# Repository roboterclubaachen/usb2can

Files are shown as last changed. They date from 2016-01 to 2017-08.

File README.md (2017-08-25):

# usb2can: Compact, isolated USB to CAN Adaptor <span style="float:right;"></span>

USB2CAN is a compact, USB-based and isolated CAN adaptor.

It is based on

 * STM32F072 Crystal-less STM32F072 ARM Cortex-M0 Processor
 * ADM3053 Isolated CAN Transceiver

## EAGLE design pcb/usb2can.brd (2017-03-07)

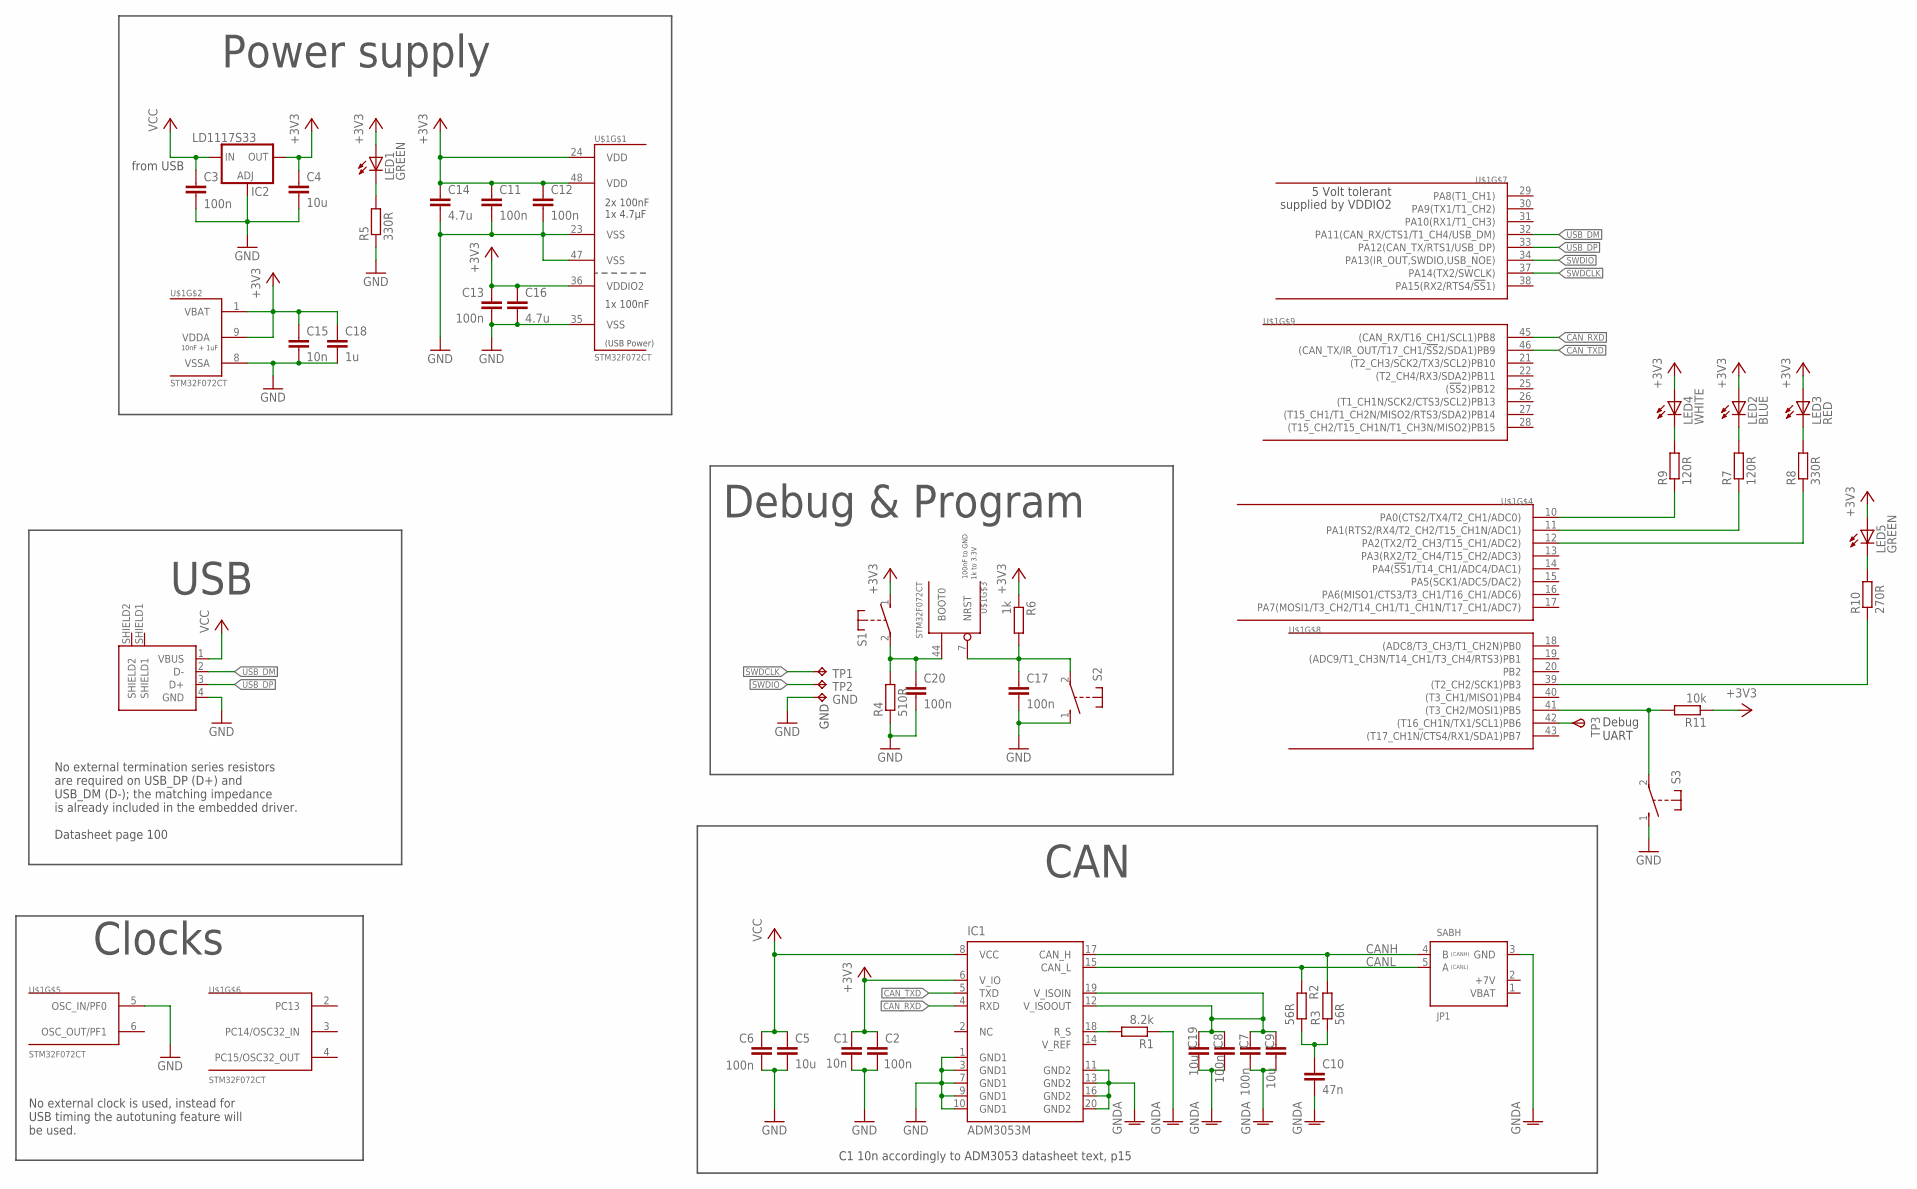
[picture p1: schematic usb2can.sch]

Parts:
C1: 10n; C0603K
C2, C3, C6: 100n; C0603K
C4, C5, C9, C19: 10u; C0805K
C7, C8: 100n; C0805K
C10: 47n; C0603K
C11, C12, C13, C17, C20: 100n; C0603
C14, C16: 4.7u; C0805K
C15: 10n; C0603
C18: 1u; C0805K
CON1: USB_A_MALESMD; USB_A_MALE_SMD
GND: TPB2,54; B2,54
IC1: ADM3053M; SO20W
IC2: LD1117S33; SOT223
JP1: SABH; 7395-05
LED1, LED5: GREEN; CHIPLED_0603
LED2: BLUE; CHIPLED_0603
LED3: RED; CHIPLED_0603
LED4: WHITE; CHIPLED_0603
R1: 8.2k; R0603
R2, R3: 56R; R0805
R4: 510R; R0603
R5, R8: 330R; R0603
R6: 1k; R0603
R7, R9: 120R; R0603
R10: 270R; R0603
R11: 10k; R0603
S1, S2, S3: MICRO_SWITCH_3X6X2.5S; MICRO_SWITCH_3X6X2.5
TP1, TP2: TPB2,54; B2,54
TP3: TPSTP07R; TP07R
U$1: STM32F072CT; TQFP48

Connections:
+3V3: C1.1, C2.1, C4.1, C11.1, C12.1, C13.1, C14.1, C15.1, C16.1, C18.1, IC1.6 (V_IO), IC2.4 (OUT), LED1.A, LED2.A, LED3.A, LED4.A, LED5.A, R6.1, R11.1, S1.1, U$1.1 (VBAT), U$1.9 (VDDA), U$1.24 (VDD), U$1.36 (VDDIO2), U$1.48 (VDD)
CANH: IC1.17 (CAN_H), JP1.4 (B), R3.2
CANL: IC1.15 (CAN_L), JP1.5 (A), R2.2
CAN_RXD: IC1.4 (RXD), U$1.45 ((CAN_RX/T16_CH1/SCL1)PB8)
CAN_TXD: IC1.5 (TXD), U$1.46 ((CAN_TX/IR_OUT/T17_CH1/!SS!2/SDA1)PB9)
GND: C1.2, C2.2, C3.2, C4.2, C5.2, C6.2, C11.2, C12.2, C13.2, C14.2, C15.2, C16.2, C17.2, C18.2, C20.2, CON1.4 (GND), GND.TP, IC1.1 (GND1), IC1.3 (GND1), IC1.7 (GND1), IC1.9 (GND1), IC1.10 (GND1), IC2.1 (ADJ), R4.1, R5.1, S2.1, S3.1, U$1.5 (OSC_IN/PF0), U$1.8 (VSSA), U$1.23 (VSS), U$1.35 (VSS), U$1.47 (VSS)
GNDA: C7.2, C8.2, C9.2, C10.2, C19.2, IC1.11 (GND2), IC1.13 (GND2), IC1.16 (GND2), IC1.20 (GND2), JP1.3 (GND), R1.1
unnamed: IC1.18 (R_S), R1.2
unnamed: C10.1, R2.1, R3.1
unnamed: LED1.C, R5.2
unnamed: C20.1, R4.2, S1.2, U$1.44 (BOOT0)
unnamed: C17.1, R6.2, S2.2, U$1.7 (NRST)
unnamed: C7.1, C8.1, C9.1, C19.1, IC1.12 (V_ISOOUT), IC1.19 (V_ISOIN)
unnamed: LED2.C, R7.2
unnamed: R11.2, S3.2, U$1.41 ((T3_CH2/MOSI1)PB5)
unnamed: LED3.C, R8.2
unnamed: LED4.C, R9.2
unnamed: R9.1, U$1.10 (PA0(CTS2/TX4/T2_CH1/ADC0))
unnamed: R7.1, U$1.11 (PA1(RTS2/RX4/T2_CH2/T15_CH1N/ADC1))
unnamed: R8.1, U$1.12 (PA2(TX2/T2_CH3/T15_CH1/ADC2))
unnamed: LED5.C, R10.2
unnamed: R10.1, U$1.39 ((T2_CH2/SCK1)PB3)
SWDCLK: TP1.TP, U$1.37 (PA14(TX2/SWCLK))
SWDIO: TP2.TP, U$1.34 (PA13(IR_OUT,SWDIO,USB_NOE))
TX: TP3.TP, U$1.42 ((T16_CH1N/TX1/SCL1)PB6)
USB_DM: CON1.2 (D-), U$1.32 (PA11(CAN_RX/CTS1/T1_CH4/USB_DM))
USB_DP: CON1.3 (D+), U$1.33 (PA12(CAN_TX/RTS1/USB_DP))
VCC: C3.1, C5.1, C6.1, CON1.1 (VBUS), IC1.8 (VCC), IC2.3 (IN)

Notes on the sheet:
CAN
No external termination series resistors are required on USB_DP (D+) and USB_DM (D-); the matching impedance is already included in the embedded driver. Datasheet page 100
USB
Clocks
No external clock is used, instead for USB timing the autotuning feature will be used.
from USB
Power supply
Debug & Program
Debug UART
C1 10n accordingly to ADM3053 datasheet text, p15

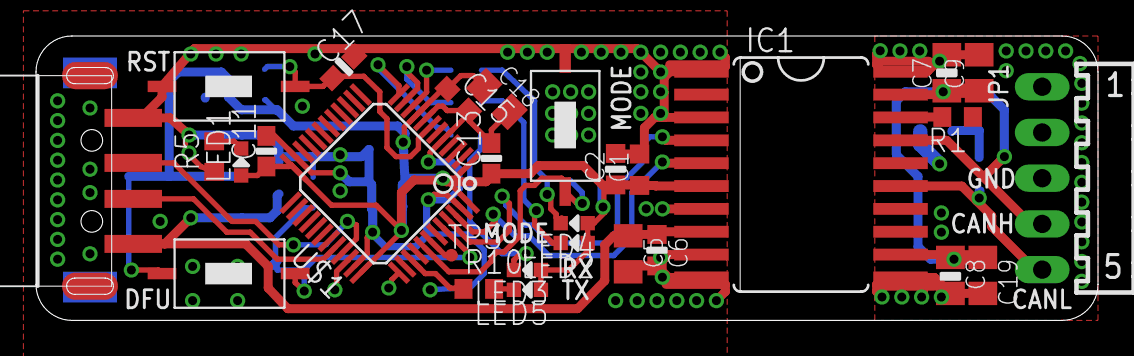
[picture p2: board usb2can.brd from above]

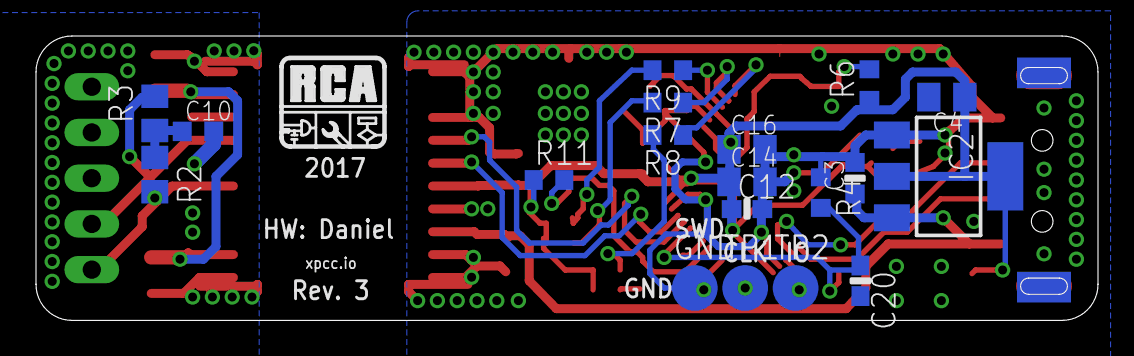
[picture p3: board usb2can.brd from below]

Board: 2 copper layers, 59.0 x 15.8 mm, 49 parts (19 on the bottom side), 28 nets.

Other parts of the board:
U$2: LOGO_SILK_BOT

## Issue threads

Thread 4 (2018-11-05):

Voltage ratings of capacitors C7, C8, C9 and C19

strongly-typed, 2018-11-05:
C7, C8, C9 and C19 are in a 0805 package. Is there a special requirement? What voltage rating has been selected in the successful prototypes? What ceramic (X7R?) is recommended?

salkinium, 2018-11-05:
cc @daniel-k @ekiwi

ekiwi, 2018-11-05:
I think the hardware was mostly done by @daniel-k.

daniel-k, 2018-11-18:
Hum, it's been quite some time and I honestly don't remeber, sorry :/

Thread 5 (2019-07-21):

Firmware?

dimecho, 2019-07-21:
A bit confused about which firmware to use? Tried "slcan CANable firmware" but it builds for STM32F042x6. DFU flashes it but CAN not working. Is there a .hex or .bin for this hardware?

daniel-k, 2019-07-21:
Have a look at https://github.com/nexulm/candleLight_fw/blob/fa7a75c04ef5fbaab253ac6e34735fadccb97d17/Makefile#L63-L67, @nexulm seems to be using the hardware and made the required changes to get it working with candleLight. Would be great to get some feedback if you try it out :)

dimecho, 2019-07-22:
Thanks,

I changed 2 things for STM32F072xB

`ASM_SRC  = system/src/cmsis/startup_stm32f072xb.S`

and

`usb2can:
          $(MAKE) CHIP=STM32F072xB BOARD=usb2can bin`

Compiled OK.

Bad news as soon as I pressed RST button magic smoke and chip burned - both red and blue LEDs stayed on. Unless I soldered something incorrectly the hardware is not 100%, did anyone actually build this? Why would STM32 burn by pressing RST?

dimecho, 2019-07-23:
Second try, works! I must have shorted something ...don't know, components are small. All works took a lot of research. Got it to work with special CandleAPI driver with cangaroo app https://github.com/normaldotcom/cangaroo/

Closed 2019-07-23.

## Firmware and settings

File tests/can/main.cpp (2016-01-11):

/* main.cpp
 *
 * Copyright (C) 2016 Kevin Laeufer <kevin.laeufer@rwth-aachen.de>
 *
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
 * You should have received a copy of the GNU General Public License
 * along with this program.  If not, see <http://www.gnu.org/licenses/>.
 */

// Tested on hardware (Rev. 1 with V_ISOIN/V_ISOOUT pins on tranceiver connected)
// on 2016-01-11 by Kevin.

#include "../usb2can_rev1.hpp"
#include <xpcc/processing/timer.hpp>

int main(void)
{
	Board::initialize();

	Board::LedBlue::set();

	// Initialize Can
	GpioInputB8::connect(Can1::Rx);
	GpioOutputB9::connect(Can1::Tx, Gpio::OutputType::PushPull);
	Can1::initialize<Board::DefaultSystemClock, Can1::Bitrate::kBps125>(9);

	// Receive every message
	CanFilter::setFilter(0, CanFilter::FIFO0,
			CanFilter::ExtendedIdentifier(0),
			CanFilter::ExtendedFilterMask(0));

	// Send a message
	xpcc::can::Message msg1(1, 1);
	msg1.setExtended(true);
	msg1.data[0] = 0x11;
	Can1::sendMessage(msg1);

	xpcc::ShortPeriodicTimer pTimer(1000);

	while (1) {
		if (Can1::isMessageAvailable()) {
			xpcc::can::Message message;
			Can1::getMessage(message);
			if(message.getLength() > 0) {
				message.data[0] = message.data[0] + 1;
				Can1::sendMessage(message);
			}
		}

		if (pTimer.execute()) {
			Board::LedBlue::toggle();

			static uint8_t idx = 0;
			xpcc::can::Message msg1(1, 1);
			msg1.setExtended(true);
			msg1.data[0] = idx;
			Can1::sendMessage(msg1);

			++idx;
		}
	}

	return 0;
}

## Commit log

2015-06-29 add Eagle STM32 library
2015-06-29 add first schematic draft
    [usb2can.brd, usb2can.sch]
2015-07-03 add STM32F072 datasheet and reference manual
2015-07-03 add some capacitors and connect USB and CAN
    [usb2can.brd, usb2can.sch]
2015-07-03 add STM32F072 Discovery board manual
2015-07-05 schematic: clock done, USB needs no series-R, debug port done, power supply revised
    [usb2can.brd, usb2can.sch]
2015-07-05 schematic: use another usb connector and add forgotten library
    [usb2can.brd, usb2can.sch]
2015-12-21 progress made by Martin
    [usb2can.brd, usb2can.sch]
2015-12-21 pcb: fix capacitor values for ADM3053
    [usb2can.brd, usb2can.sch]
2015-12-22 pcb: final routing and small schamtic fixes
    * Testpad for UART TX
    * 4 User LEDs
    * 1 User Button
    * RCA CAN-connector
    * Bypass capacitor for BOOT0
    [usb2can.brd, usb2can.sch]
2015-12-22 pcb: add GERBER export for OSHPARK
    [usb2can.GBL, usb2can.GBO, usb2can.GBS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]
2015-12-22 final order of rev1
    [usb2can.brd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]
2016-01-07 pcb: update schematic with correct values
    [usb2can.brd, usb2can.sch]
2016-01-11 [tests] add blink test
    [project.cfg]
2016-01-11 leds are low active => invert signals
2016-01-11 [tests] blink: use button
2016-01-11 [tests] add CAN test
    [project.cfg]
2016-01-11 pcb: fix CAN transceiver V_ISOIN and V_ISOOUT not connected
    [usb2can.brd, usb2can.sch]
2016-01-11 pcb: adapt resistor values for LEDs
    [usb2can.brd, usb2can.sch]
2016-01-12 [tests] we only have a 48 pin controller
    [project.cfg]
2017-01-20 pcb: increment revision and export for OSHPark
    [usb2can.brd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]
2017-01-20 pcb: add bottom pads for USB connector
    [usb2can.brd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]
2017-03-07 schematic: remove wire crossing between CAN_H and CAN_H.
    [usb2can.sch]
2017-03-07 schematic: rename unnamed wires to CANH and CANL.
    [usb2can.brd, usb2can.sch]
2017-03-07 schematic: Bypass Capacitors and Silk Screen
    - Bypass capacitors: nearest capacitor should be the smallest.
    - Add label to 100n capacitors
    - Add label to LEDs
    [usb2can.brd, usb2can.sch]
2017-03-07 pcb: Create Rev3 Gerbers and save new viewport.
    [usb2can.brd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]

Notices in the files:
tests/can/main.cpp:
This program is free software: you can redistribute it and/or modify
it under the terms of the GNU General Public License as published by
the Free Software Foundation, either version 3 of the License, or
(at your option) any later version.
